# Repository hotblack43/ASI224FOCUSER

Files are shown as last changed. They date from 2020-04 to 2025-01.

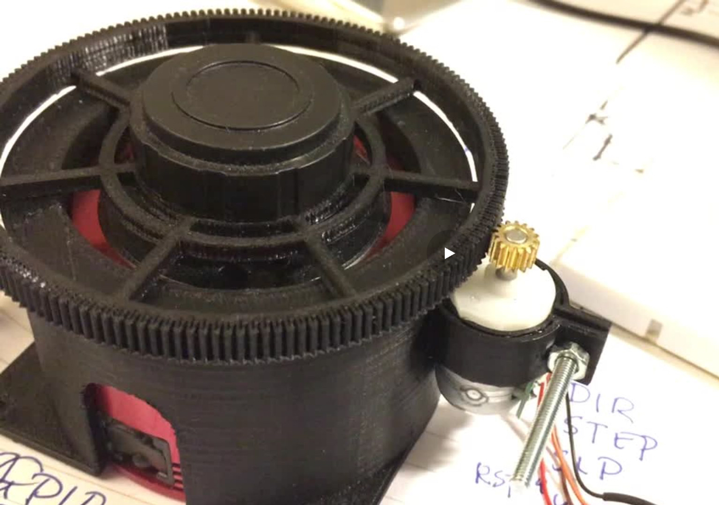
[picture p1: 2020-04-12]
ASI224_Focuser.jpg

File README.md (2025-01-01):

# ASI224FOCUSER

1) The ASI224 camera from ZWO can be focused by twisting the lens in its thread-mount. In case your camera is mounted in an unacessible place you may wish to be able to focus it remotely. This is my project to enable that.

2) In this project, the camera is connected by USB to an online Raspberry Pi (3B+ in my case) and by logging on to that Raspberry over the internet I can go to a terminal and there issue commands to take images as well as run a python code which I am distributing in this Github, which allows turning of the lens in its thread by use of a geared stepper-motor and a cog-wheel mounted around the lens.

3) The project files consist of OPENSCAD files (in .scad format so you can edit and make them better) and one python3 code which, when installed with the right libraries, as well as various enabling electronics, allows turning the lens left or right by so many steps. There is also a hardware list covering the camera and the lens, the dome, and various cables and electronics. And a photo showing the thing in its glory!

April 12 2020.

PS from January 2025: The systems survived well for several years on a roof in a city. The dome I used turned yellow from the Sunlight and needs to be exchanged. But there are ideas for what to do. The basic system - cogwheel and remote control and stepper motors never let me down, so I can recommend it as far as that goes.

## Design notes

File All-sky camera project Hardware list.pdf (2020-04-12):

## Hardware list for my ZWO ASI224 all-sky camera focuser

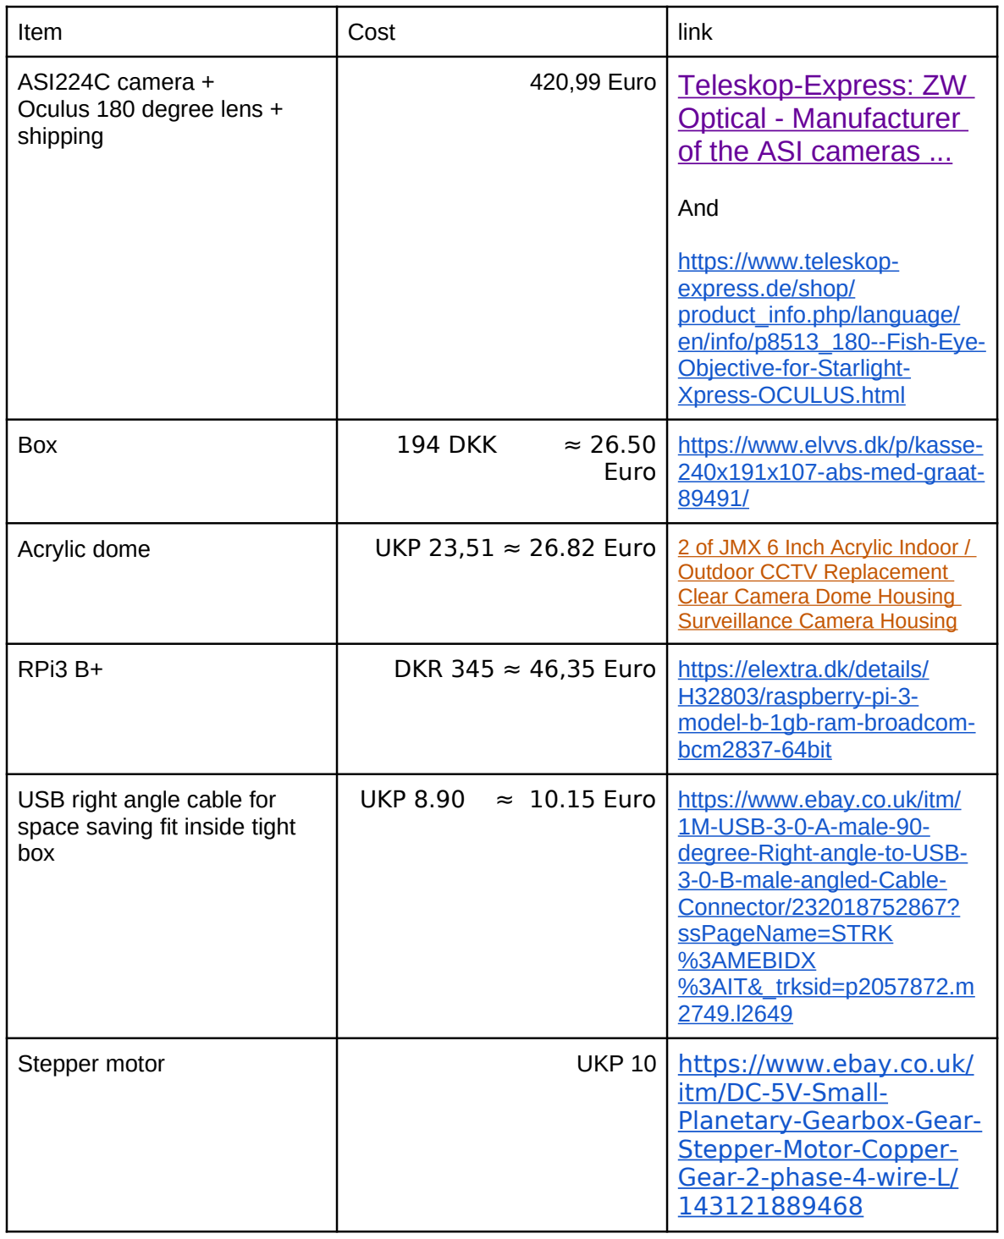
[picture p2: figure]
Item; Cost; link; ASI224C camera + Oculus 180 degree lens + shipping; 420,99 Euro; Teleskop-Express: ZW; Optical - Manufacturer of the ASI cameras ...; And; https://www.teleskop- express.de/shop/ product_info.php/language/ en/info/p8513_180--Fish-Eye- Objective-for-Starlight- Xpress-OCULUS.html; Box; 194 DKK; Euro; https://www.elvvs.dk/p/kasse- 240x191x107-abs-med-graat- 89491/; Outdoor CCTV Replacement Clear Camera Dome Housing Surveillance Camera Housing; H32803/raspberry-pi-3- model-b-1gb-ram-broadcom- bcm2837-64bit; USB right angle cable for space saving fit inside tight box; 1M-USB-3-0-A-male-90- degree-Right-angle-to-USB- 3-0-B-male-angled-Cable- Connector/232018752867? ssPageName=STRK %3AMEBIDX %3AIT&_trksid=p2057872.m 2749.l2649; itm/DC-5V-Small- Planetary-Gearbox-Gear- Stepper-Motor-Copper- Gear-2-phase-4-wire-L/ 143121889468

Acrylic dome | UKP 23,51 ≈ 26.82 Euro | 2 of JMX 6 Inch Acrylic Indoor /
RPi3 B+ | DKR 345 ≈ 46,35 Euro | https://elextra.dk/details/
UKP 8.90 ≈ 10.15 Euro | https://www.ebay.co.uk/itm/
Stepper motor | UKP 10 | https://www.ebay.co.uk/

Polou stepper motor
controller

https://www.ebay.co.uk/
itm/A4988-Stepper-Motor-Driver-3D-Printer-Driver-Module-Reprap-Board-with-Heatsink/
402022001445?
hash=item5d9a60eb25:
m:mHSZ6H25zYD8hvE9u
e2R0aw (https://www.ebay.co.uk/itm/A4988-Stepper-Motor-Driver-3D-Printer-Driver-Module-Reprap-Board-with-Heatsink/402022001445)
FT232H GPIO/USB converter | https://www.ebay.co.uk/ itm/Adafruit-FT232H- Breakout-General- Purpose-USB-to-GPIO- SPI-I2C- ADA2264/232427166390 ?
| epid=2256534785&hash =item361dbd1ab6:g:t7g AAOSwawVZew82 (https://www.ebay.co.uk/itm/Adafruit-FT232H-Breakout-General-Purpose-USB-to-GPIO-SPI-I2C-ADA2264/232427166390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)
Power supply | https:// www.amazon.co.uk/gp/ product/B07MY3NZ18/ ref=ppx_yo_dt_b_asin_i mage_o06_s00? ie=UTF8&psc=1 (https://www.amazon.co.uk/gp/product/B07MY3NZ18/ref=ppx_yo_dt_b_asin_image_o06_s00?ie=UTF8&psc=1)

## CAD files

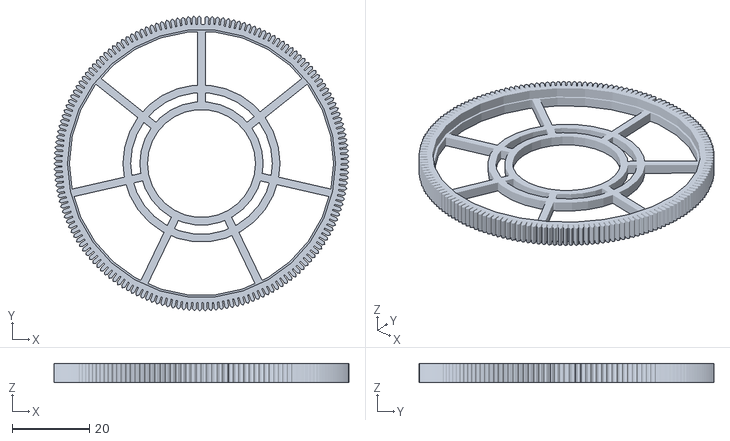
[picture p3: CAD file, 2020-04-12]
focus_ring_gear_ZWO_Mk_X.stl
76.5 x 76.5 x 5.00

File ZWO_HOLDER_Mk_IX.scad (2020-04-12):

        echo(version=version());
        
        // Holder for ZWO ASI 224 MC camera, and a stepper-motor, with baseplate
        // Peter Thejll, peter.thejll@gmail.com, March 2019.
        
        // Universals
        epsilon=0.05; // Small clearance to build in
        
        ID = 62.45;    // Camera body diameter
        wall = 2.1;  // Wall thickness of parts
        OD = (ID+2*wall)/2;  // Outer diameter of camera holder
        body_height = 28.1+epsilon+0.4 ; // Height of the red ZWO ASI224 to the first ledge
        kerf = 12.2; // height of step on red body up to movable lens-part 
        aperture=51; // Diameter of ledge with lens
        port=15; // width and height of USB port
        screws=3.15; // Diameter of screw-holes to be used for clip
        offset=-6+9; // Distance below ledge of clip top
        motor_h1=10; // Height of the clip part
        motor_D=14.9+0.4; // Diameter of the stepper motor body
        gap=wall/3; // Gap in the lips of the clip holding camera
       
       // fudge
        magic=40.55-(ID+wall+motor_D)/2;
        
        difference(){
        // Do the camera-holder first
            co();
        // Now make port holes in it - first one
                translate([ID/2,0,-0.01])
                    linear_extrude(height=port+2)
                    square([port,port], center = true);
        // Then the second one at right angles
                translate([0,ID/2,-0.01])
                    linear_extrude(height=port+2)
                    square([port,port], center = true);
        // Then the third one at right angles
        translate([0,-ID/2,-0.01])
            linear_extrude(height=port+2)
            square([port,port], center = true);
            
    // Now also some gaps at the top edge
        // Nfirst one
    //            translate([ID/2,0,body_height])
    //                linear_extrude(height=port+2)
    //                square([port,port/3], center = true);
        // Then the second one at right angles
    //            translate([0,ID/2,body_height])
    //                linear_extrude(height=port+2)
    //                square([port/3,port], center = true);
        // Then the third one at right angles
    //    translate([0,-ID/2,body_height])
     //       linear_extrude(height=port+2)
     //       square([port/3,port], center = true);      
            
// Subtract a 90 degree cylinder  
rotate(a=90,v=[1,0,0]) 
rotate(a=90,v=[0,1,0]) 
translate([0,body_height-10,+15])
cylinder(h=1000,r=7.5);
// Subtract another cylinder  
rotate(a=90,v=[1,0,0]) 
rotate(a=180,v=[0,1,0]) 
translate([0,body_height-10,-35])
cylinder(h=1000,r=7.5); 

        }
        
        
        // And then add the clip
  //     translate([-ID/2-motor_D/2-wall-0.6,
         translate([-(ID+wall+motor_D)/2-magic,
                        0,
                        body_height+kerf-motor_h1-offset-3.5])
         rotate(a=180,v=[0,0,1])
            clip(motor_D/2,wall,motor_h1,screws);
        
        //=================================================================
        // Define a bunch of modules
        
        module clip_part(motor_D,wall,motor_h1){
               
        // Extrude a cylinder
            color("green")
            translate([0, 0, 0])
                rotate_extrude($fn = 100)
                    polygon( points=[
                    [motor_D,0],
           [motor_D+wall,0],
           [motor_D+wall,motor_h1],
           [motor_D,motor_h1],
           [motor_D,0] 
        ]);
        // The 'tabs'
            translate([0,0,0])
            linear_extrude(height=motor_h1)
               polygon( points=[
                    [motor_D,-wall],
                     [motor_D+4*wall,-wall],         
                     [motor_D+4*wall,wall],
                              [motor_D,wall],
                   [motor_D,-wall]
                    ]);
             };
            
        module wall(gap){

            r=motor_D/2;
            translate([0,0,-motor_h1/3])
            linear_extrude(height=2*motor_h1)
               polygon( points=[
                     [0,-gap],
                     [3*r,-gap],         
                     [3*r,gap],
                     [0,gap],
                     [0,-gap]
                    ]);   
            
            };
            
         module hole(screws){
             r=motor_D/2;
             translate([r+wall*2,-10,motor_h1/2])
             rotate(a=-90,v=[1,0,0]) cylinder(d=screws,h=500,centre=true);   
             };
        
        
         // Now for the difference of the co and a wall
             
        module clip(r,wall,motor_h1,screws){
            difference(){
                // Between
                clip_part(r,wall,motor_h1);
                // and ..
                wall(gap);     
                hole(screws); 
             }
         };
         
        
        module co(){
        // Shroud
        color("green")
            translate([0, 0, 0])
                rotate_extrude($fn = 100)
                    polygon( points=[
                    [ID/2.,0], 
                    [ID/2.,body_height], 
                    [ID/2.-(ID/2-aperture/2),body_height], 
                    [ID/2.-(ID/2-aperture/2),body_height+kerf],
                    [ID/2.+wall,body_height+kerf],
                    [ID/2.+wall,0]
                    ]);
           
        
         // Subtract a cylinder from a baseplate to allow for camera insert
        
            difference() {
         // Baseplate          
            color("red")
            translate([0, 0, 0])
                    linear_extrude(height =wall)
                    square([ID+wall*2-1.4,ID+wall*2-1.4], center = true);
        
        // Hole in baseplate for camera insert
                translate([0,0,-0.1]) cylinder(d=ID, h=9.002, center=true);
        // Mounting holes
                translate([29,29,-0.1]) cylinder(d=screws,h=10,centre=true);
                translate([-29,29,-0.1]) cylinder(d=screws,h=10,centre=true);
                translate([29,-29,-0.1]) cylinder(d=screws,h=10,centre=true);
                translate([-29,-29,-0.1]) cylinder(d=screws,h=10,centre=true);
                
        
            }
        }    
                 

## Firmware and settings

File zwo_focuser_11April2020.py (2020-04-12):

## Usage (typical)
# sudo python zwo_focuser_11April2020.py left 500
#
## Focus motor software using a geared bipolar stepper motor
## Uses an FT232H to generate GPIO values as input for 
## a Polou A4988 that drives the motor and is fed 8 VDC.

# Wiring:
# Connect C0 on FT232H to DIR on A4988 - i.e. pin DIR
# Connect C1 on FT232H to STP on A4988 - i.e. pin STEP
# Connect C2 on FT232H to SLP on A4988 - i.e. pin SLP
# Connect C3 on FT232H to RST on A4988 - i.e. pin RST
# Connect C4 on FT232H to ENA on A4988 - i.e. pin ENABLE
# Import standard Python sys and time library.
import sys
import time

# Import GPIO and FT232H modules.
import Adafruit_GPIO as GPIO
import Adafruit_GPIO.FT232H as FT232H
print('Done importing libs ...')

# Read arguments https://www.youtube.com/watch?v=kQFKtI6gn9Y
#------------------------------------------------------------------------
print("This is the name of the script: ", sys.argv[0])
print("Number of arguments: ", len(sys.argv))
print("The arguments are: " , str(sys.argv))
#------------------------------------------------------------------------
#read the direction and number of steps; if steps are 0 exit
try:
    direction = sys.argv[1]
    steps = int(float(sys.argv[2]))
except:
    steps = 0

print("You told me to turn",steps," steps.", steps) 
print("In the direction : ",direction) 
#------------------------------------------------------------------------
#------------------------------------------------------------------------

# Temporarily disable the built-in FTDI serial driver on Mac & Linux platforms.
FT232H.use_FT232H()
# Create an FT232H object that grabs the first available FT232H device found.
ft232h = FT232H.FT232H()

# Configure digital outputs using the setup function.
# Note that pin numbers 0 to 15 map to pins D0 to D7 then C0 to C7 on the board.
ft232h.setup(8, GPIO.OUT) # Make pin C0 a digital output.
ft232h.setup(9, GPIO.OUT) # Make pin C1 a digital output.
ft232h.setup(10, GPIO.OUT) # Make pin C2 a digital output.
ft232h.setup(11, GPIO.OUT) # Make pin C3 a digital output.
ft232h.setup(12, GPIO.OUT) # Make pin C4 a digital output.

# Set pin C0 to a LOW level 
ft232h.output(8, GPIO.LOW)
# Set pin C1 to a LOW level 
ft232h.output(9, GPIO.LOW)

#------------------------------------------------------------------------
#------------------------------------------------------------------------
#set 8 to LOW for left and HIGH for right
if direction == 'left':
    ft232h.output(8, GPIO.LOW)
elif direction == 'right':
    ft232h.output(8, GPIO.HIGH)
#------------------------------------------------------------------------
#------------------------------------------------------------------------

# Turn ON the juice to motor
print("ENABLING device, now") 
# Set pin C4 to a LOW level thus ENABLING the device
ft232h.output(12, GPIO.LOW)

ft232h.output(10, GPIO.HIGH)
ft232h.output(11, GPIO.HIGH)

#------------------------------------------------------------------------
#------------------------------------------------------------------------
StepCounter = 0
WaitTime = 0.001    ## This value may be motor-specific. If set wrong 
                    ## motor whines or grumbles and may not follow DIR commands
# Start main loop
while StepCounter < steps:

    #turning the gpio on and off tells the easy driver to take one step
    ft232h.output(9, GPIO.HIGH)
    ft232h.output(9, GPIO.LOW)
    StepCounter += 1

    #Wait before taking the next step...this controls rotation speed
    time.sleep(WaitTime)
#------------------------------------------------------------------------
#------------------------------------------------------------------------


# Turn OFF the juice to motor

ft232h.output(10, GPIO.LOW)
ft232h.output(11, GPIO.LOW)
print("POWER TO MOTOR IS OFF, now") 
# Set pin C4 to a HIGH thus DISABLING the device
ft232h.output(12, GPIO.HIGH)
print("DEVICE DISABLED, now") 

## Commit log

2020-04-12 Add files via upload
    First upload fo files for the ASI224 ZWO camera focuser project.
    [ZWO_HOLDER_Mk_IX.scad, focus_ring_gear_ZWO_Mk_X.stl]
2020-04-12 Add files via upload
    Python code for running focuser.
    Requires some Adafruit libraries - see start of file.
    Python3 is required also.
    Start of file shows how to run, and do the wiring.
2020-04-12 Add files via upload
    Added image of what the camera holder and focus ring looks like, with the stepper motor on place.
